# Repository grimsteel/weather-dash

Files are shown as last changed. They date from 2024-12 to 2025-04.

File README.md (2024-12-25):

# Weather Dashboard

> LCD weather dash powered by an ESP32-S2 and a 1.8" TFT

## Case

[Onshape](https://cad.onshape.com/documents/d06c112e58f115f3ec29811b/w/2a8c46b6d89bea48d93f043a/e/2a97cfce612bd0256a92786b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)

**Switch to the "Demo" named view!**

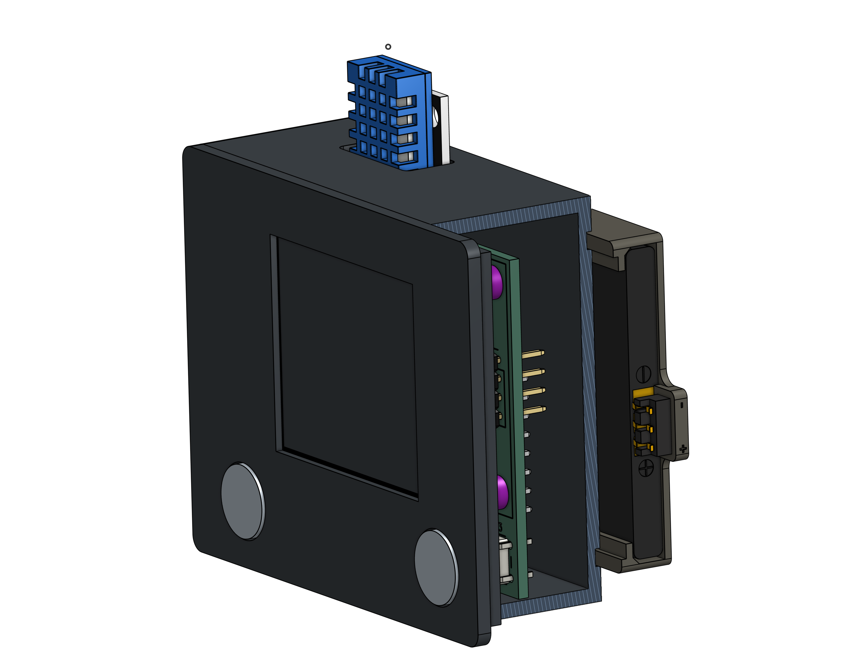
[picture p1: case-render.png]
case render


## PCB

[Kicanvas](https://kicanvas.org/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)

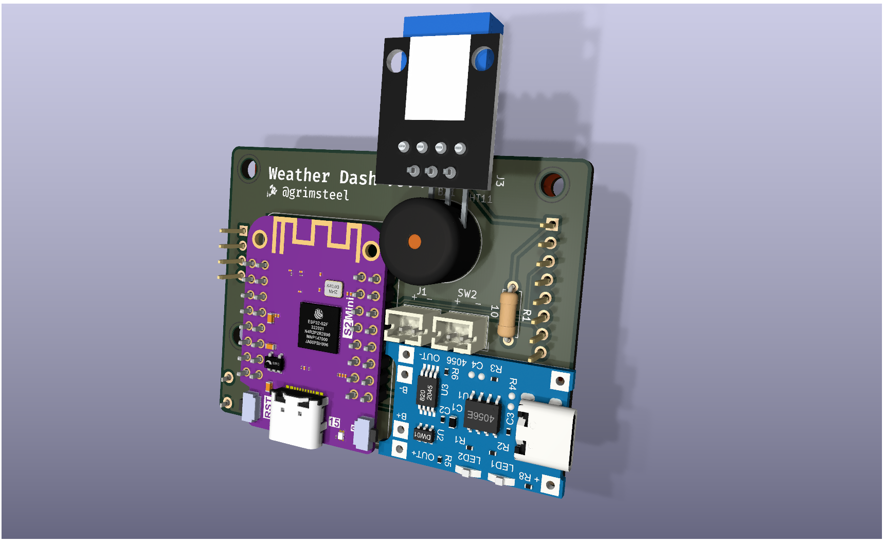
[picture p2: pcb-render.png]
pcb render


### Major Components:

- Wemos S2 Mini
- 1.8" TFT
- DHT11 temp/humidity sensor
- Li-ion battery charger

### Voltage Calculations:

1. ESP32-C3 requires 3.0-3.6V input voltage
2. The LDO technically requires 4.3V for a stable 3.3V, _but_ starts providing 3.0V at an input of ~3.1V
3. The battery is 3.8V
4. The 1N5817 Schottky has a voltage drop of 0.25V at 200 mA
5. Therefore, the LDO will be provided with 3.45V and will output 3.2-3.3V

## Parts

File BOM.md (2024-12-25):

# BOM

- 1x Wemos C3 Mini
  
  LDO Datasheet: https://stm32-base.org/assets/pdf/regulators/ME6211.pdf
  Schematic: https://www.wemos.cc/en/latest/_static/files/sch_c3_mini_v2.1.0.pdf
- 1x 1.8" ST7355 TFT
- 2x JST PH-2.0 connector + wires/plug

  https://www.aliexpress.us/item/3256806041370367.html ($0.99 welcome / $1.08) 5 sets 2P
- 1x 3 pin SPDT switch - 0.5A

  https://www.aliexpress.us/item/2255800513009332.html ($0.82 / $0.84) 10 pcs
  https://www.aliexpress.us/item/3256803752541650.html ($0.99 gift / $2.36)
  SS-12F15
- 1x 1N5817 diode

  https://www.diodes.com/assets/Datasheets/1N5817-1N5819.pdf
  https://www.aliexpress.us/item/3256801365779334.html ($0.91 50pcs welcome)
  https://www.aliexpress.us/item/2255801086330895.html ($1.03 50pcs)
- 1x TP4056 board - choose "18650 Type C" - make sure it has 6 holes total (w/ protection)

  https://dlnmh9ip6v2uc.cloudfront.net/datasheets/Prototyping/TP4056.pdf
  https://www.aliexpress.us/item/3256807605386962.html ($0.61 gift / $1.35)
  https://www.aliexpress.us/item/3256806824094515.html ($0.99 gift 5 pcs / $2.56 gift 5 pcs)
  https://www.aliexpress.us/item/3256804241424963.html ($1.29 5 pcs)
  https://www.aliexpress.us/item/3256807979673795.html ($0.80 gift / $2.28)
  https://www.aliexpress.us/item/3256807931985778.html ($0.99 welcome / $1.08)
  https://www.aliexpress.us/item/3256807944765163.html ($1.45 5 pcs)
  https://www.aliexpress.us/item/3256808009574936.html ($0.99 welcome 5 pcs / $3.77 5 pcs)
- 2x Tactile button cap - gray

  https://www.aliexpress.us/item/2251832842559353.html ($0.99 gift / $2.93 20pcs)
  https://www.aliexpress.us/item/2251832629712765.html ($0.99 gift / $1.53 100pcs)
  https://www.aliexpress.us/item/2251832660080884.html ($0.99 gift / $2.50 100pcs)
- 3x M3 Heatset Inserts 

  https://www.aliexpress.us/item/3256803396040989.html ($0.99 gift / $1.84) M3(OD4.5mm) 3.5mm 50pcs
- M3 heatset insert soldering iron tip

  https://www.aliexpress.us/item/3256806515637370.html ($0.99 gift / $2.37)
- 1x 3pin Battery Spring compression contact (BC-35-3P)

  https://www.aliexpress.us/item/2255800016944760.html (0.99 gift / $2.28) 5pcs 3pin male
  
- 1x DHT11 board
- 2x basic push button
- 1x 10 ohm resistor THT
- 2x 10K resistor THT
- 1x 1x3 female header
- 3x 1x8 male header
- 1x 1x4 male header

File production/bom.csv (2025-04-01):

Designator | Footprint | Quantity | Value | LCSC Part #
BZ1 | Buzzer_12x9.5RM7.6 | 1 | Buzzer
D1 | D_DO-41_SOD81_P7.62mm_Horizontal | 1 | 1N5817
J1 | JST_PH_B2B-PH-K_1x02_P2.00mm_Vertical | 1 | Conn_01x02_Pin
J3 | DHT11 | 1 | Conn_01x03_Socket
R1 | R_Axial_DIN0207_L6.3mm_D2.5mm_P7.62mm_Horizontal | 1 | 10
SW1, SW3 | SW_PUSH_6mm_H4.3mm | 2 | SW_Push
SW2 | JST_PH_B2B-PH-K_1x02_P2.00mm_Vertical | 1 | SW_SPST
U1 | WEMOS_S2_Mini | 1 | WEMOS_S2_Mini
U2 | TFT_ST7735_SD | 1 | TFT_ST7735_SD
U3 | TP4056 | 1 | ~

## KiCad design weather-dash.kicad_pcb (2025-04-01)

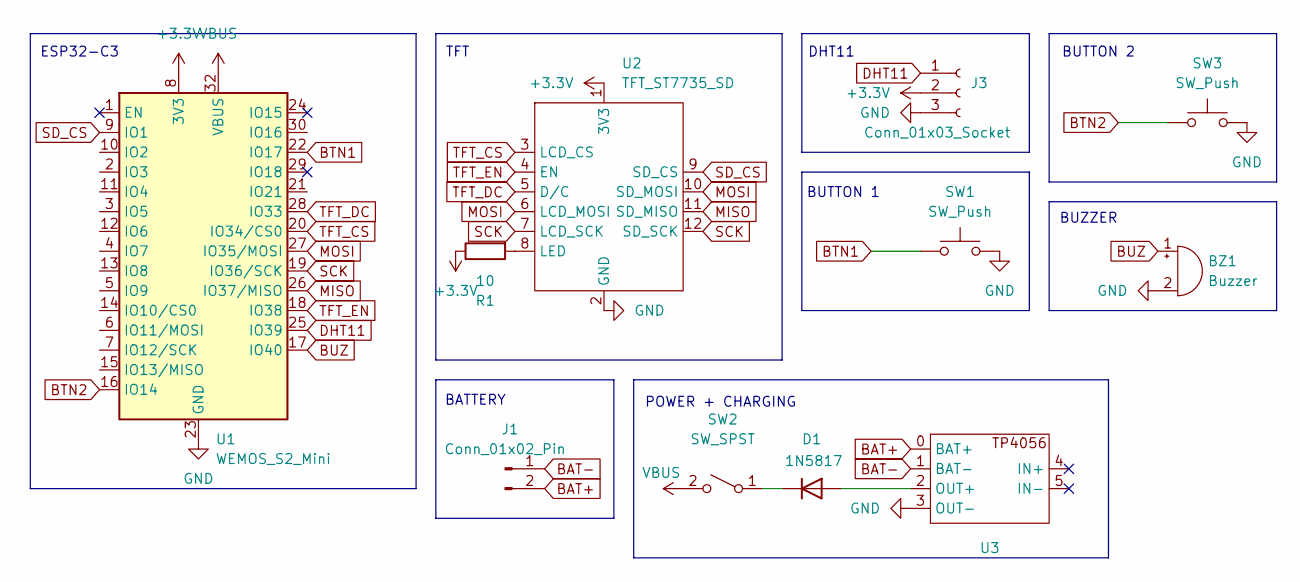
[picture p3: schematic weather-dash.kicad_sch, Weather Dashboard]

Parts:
BZ1: Buzzer; Buzzer_12x9.5RM7.6
D1: 1N5817; D_DO-41_SOD81_P7.62mm_Horizontal
J1: Conn_01x02_Pin; JST_PH_B2B-PH-K_1x02_P2.00mm_Vertical
J3: Conn_01x03_Socket; DHT11
R1: 10; R_Axial_DIN0207_L6.3mm_D2.5mm_P7.62mm_Horizontal
SW1, SW3: SW_Push; SW_PUSH_6mm_H4.3mm
SW2: SW_SPST; JST_PH_B2B-PH-K_1x02_P2.00mm_Vertical
U1: WEMOS_S2_Mini
U2: TFT_ST7735_SD
U3: TP4056

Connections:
+3.3V: J3.2, R1.1, U1.8 (3V3), U2.1 (3V3)
BAT+: J1.2, U3.0 (BAT+)
BAT-: J1.1, U3.1 (BAT-)
BTN1: SW1.1, U1.22 (IO17)
BTN2: SW3.1, U1.16 (IO14)
BUZ: BZ1.1 (+), U1.17 (IO40)
DHT11: J3.1, U1.25 (IO39)
GND: BZ1.2 (-), J3.3, SW1.2, SW3.2, U1.23 (GND), U2.2 (GND), U3.3 (OUT-)
MISO: U1.26 (IO37/MISO), U2.11 (SD_MISO)
MOSI: U1.27 (IO35/MOSI), U2.6 (LCD_MOSI), U2.10 (SD_MOSI)
unnamed: D1.2 (A), U3.2 (OUT+)
unnamed: D1.1 (K), SW2.1 (A)
unnamed: R1.2, U2.8 (LED)
SCK: U1.19 (IO36/SCK), U2.7 (LCD_SCK), U2.12 (SD_SCK)
SD_CS: U1.9 (IO1), U2.9 (SD_CS)
TFT_CS: U1.20 (IO34/CS0), U2.3 (LCD_CS)
TFT_DC: U1.28 (IO33), U2.5 (D/C)
TFT_EN: U1.18 (IO38), U2.4 (EN)
VBUS: SW2.2 (B), U1.32 (VBUS)

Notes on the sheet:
BUTTON 2
BUTTON 1
ESP32-C3
POWER + CHARGING
TFT
DHT11
BUZZER
BATTERY

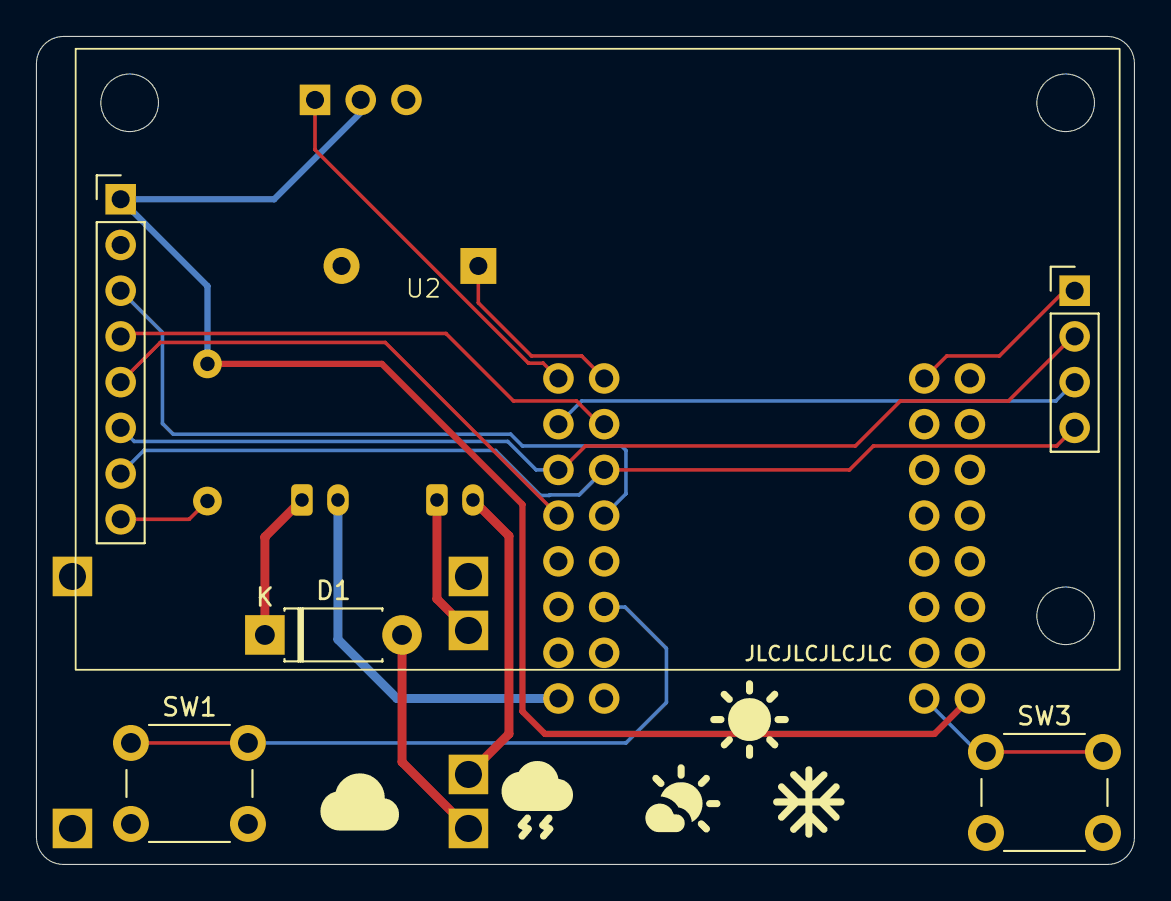
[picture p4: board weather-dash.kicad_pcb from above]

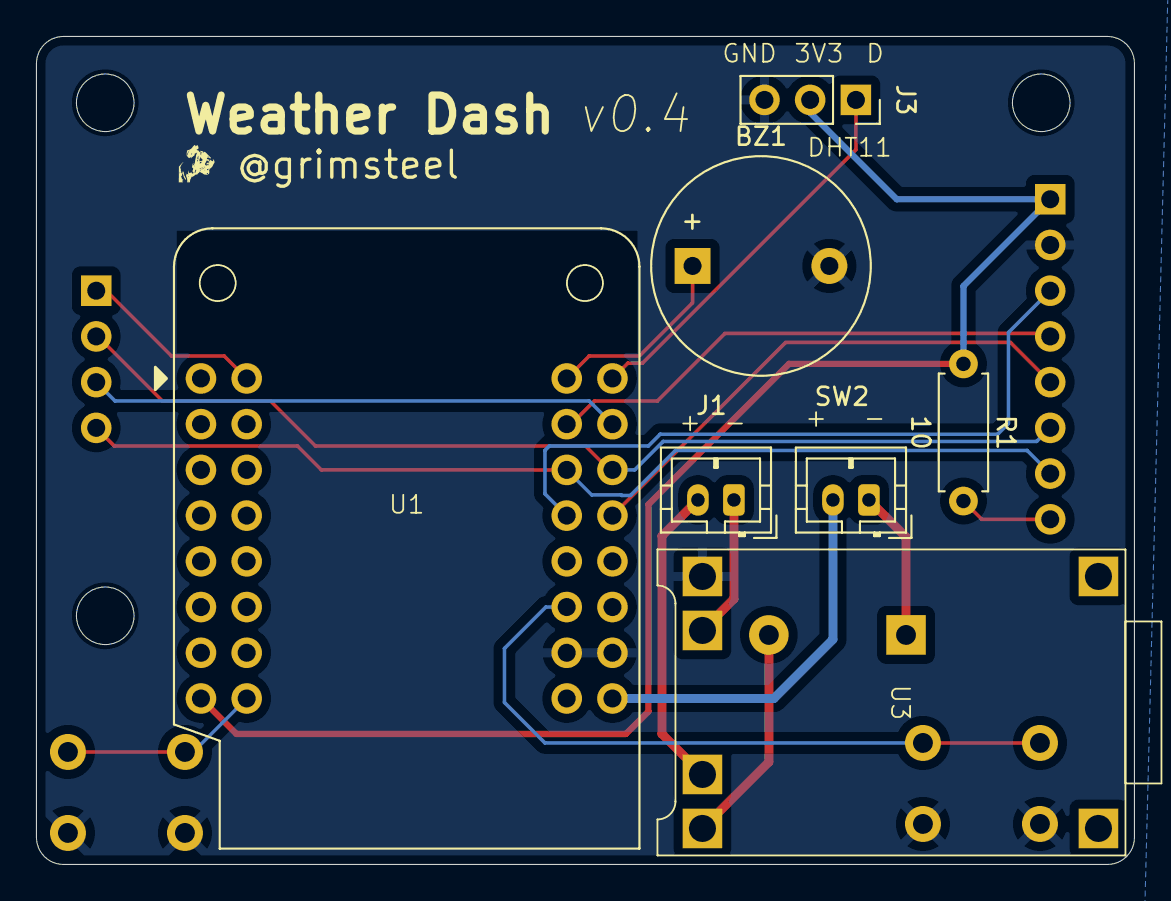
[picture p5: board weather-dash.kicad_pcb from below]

Board: 2 copper layers, 61.0 x 46.0 mm, 11 parts (7 on the bottom side), 19 nets.

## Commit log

2024-12-13 some changes
    idk what they are
    [weather-dash.kicad_pcb, weather-dash.kicad_sch]
2024-12-25 more pcb changes
    [weather-dash.kicad_pcb, weather-dash.kicad_sch]
2025-01-26 pcb updates
2025-04-01 update pcb format
    [bom.csv, designators.csv, positions.csv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]
